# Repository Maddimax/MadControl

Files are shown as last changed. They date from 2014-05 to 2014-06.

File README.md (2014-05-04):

This contains all the files necessary to build your own Remote control ( or rather will soon )

# Hardware

The schematics and pcb files were created with [KiCad](http://www.kicad-pcb.org/display/KICAD/KiCad+EDA+Software+Suite)

# Software

All code was written with the standard Arduino IDE

# BOM 

Contains a list of all the components necessary

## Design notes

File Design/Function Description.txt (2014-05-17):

Screen:
	- 480x272
	- 32 bit ( 24 + 8 alpha )

Setup
- Calibrate
- Global Curves
	- Expo Display
		- Amount
	- Linear Display
		- Amount
	- Affected Channel checkboxes

- Analog InputChannels
	- Channel (x8)
		- Curves
			- Expo
			- Linear
			- 7-point
			- Result curve
		- Destination ( Output Channel / Function )
			- Liste
		- Settings
			- Bipolar / Unipolar
- Digital Input Channels
	- Channel (16)
		- Push/Switch - Button

- Macros
	- User mappings ( 8 )
		- Function Select: ( Liste )
			* Output channel ( 0-1024 )
				- Switch select
					- + Switch ( Select 0-16 )
					- - Switch ( Select 0-16 )
				- Num Values
					- Values

			* Trim(n) ( 0-1024 )
				- Switch select
					- + Switch ( Select 0-16 )
					- - Switch ( Select 0-16 )

			* Throttle Hold ( 0/1 )
				- Select Switch ( radio )
				- If button == Push
					* Hold / Toggle
				- If Button == Switch
					* -

- Output Channels ( 8+ )
	- Channel
		- Min/Max Werte

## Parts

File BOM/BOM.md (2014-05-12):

# Kits:

* Gameduino 2 		: (http://excamera.com/sphinx/gameduino2/)
* Arduino Mega 2560 : (http://arduino.cc/de/Main/ArduinoBoardMega2560)
* OrangeTx DIY      : [HK-OrangeTx-DIY-Module](http://www.hobbyking.com/hobbyking/store/__40205__OrangeRX_DSMX_DSM2_2_4GHz_DIY_Transmitter_Module.html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)

# Components

* LTC2309           : [HBE-Shop-LTC2309](https://hbe-shop.de/Art-2294612-LINEAR-TECHNOLOGY-LTC2309CFPBF-A-D-WANDLER)
* TCA9535           : [HBE-Shop-TCA9535](https://hbe-shop.de/Art-2335659-TEXAS-INSTRUMENTS-TCA9535PWR-I-O-EXPANDER-16BIT-I2C-SMBUS-TSSOP-24)
* 2 Axis Gimbal     : [Robotshop-GIM01](http://www.robotshop.com/eu/en/axis-joystick-gim.html)
* 10nf              : Ceramic SMD
* 0.1nf             : Ceramic SMD
* 2.2nf             : Ceramic SMD
* 10kΩ				: SMD
* 1.5kΩ				: SMD
* S1G (Diode)		: SMD
* Pin header        : [Conrad-PinHeader](http://www.conrad.de/ce/de/product/741146/Stiftleiste-RM-254-gerade-Pole-1-x-40-10120183-BKL-Electronic-Inhalt-1-St/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)
* Pin Header (f)    : [Conrad-PinHeader(f)](http://www.conrad.de/ce/de/product/740668/Einreihige-Buchsenleiste-RM-254-Pole-1-x-36-10120802-BKL-Electronic-Inhalt-1-St/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)

# Enclosures
* Shapeways         : TBD
* Thingyverse       : TBD

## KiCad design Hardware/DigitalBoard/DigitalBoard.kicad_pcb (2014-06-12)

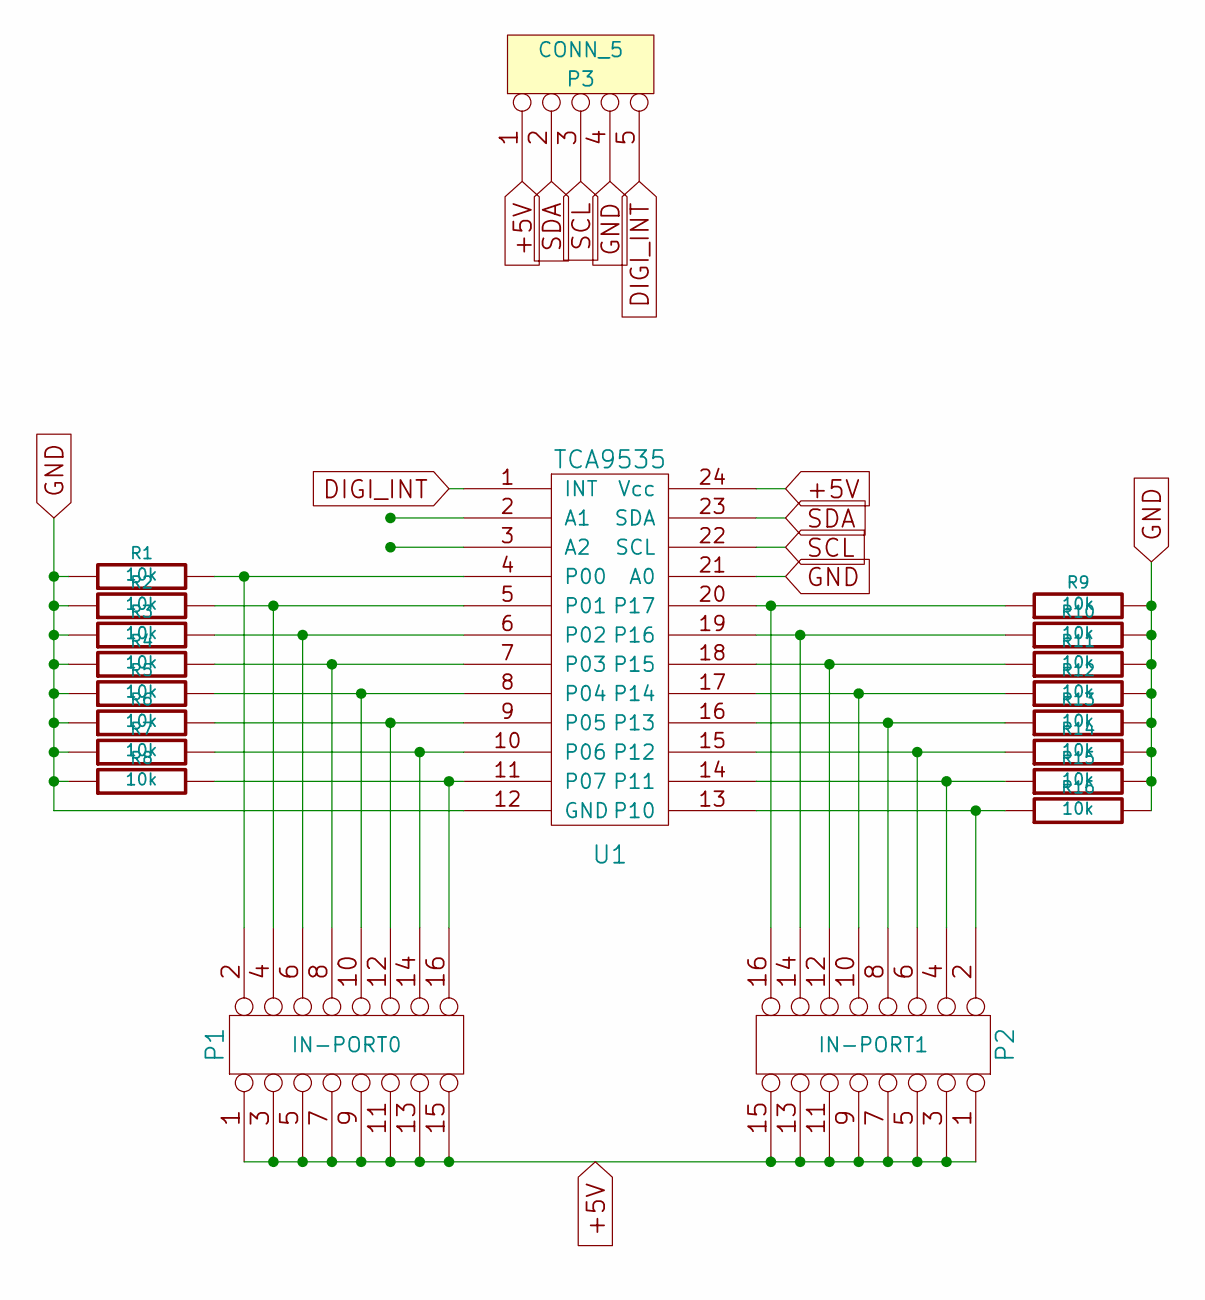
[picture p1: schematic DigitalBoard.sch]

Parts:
P1: IN-PORT0
P2: IN-PORT1
P3: CONN_5
R1, R2, R3, R4, R5, R6, R7, R8, R9, R10, R11, R12, R13, R14, R15, R16: 10k
U1: TCA9535

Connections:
+5V: P1.1, P1.3, P1.5, P1.7, P1.9, P1.11, P1.13, P1.15, P2.1, P2.3, P2.5, P2.7, P2.9, P2.11, P2.13, P2.15, P3.1, U1.24 (Vcc)
DIGI_INT: P3.5, U1.1 (INT)
GND: P3.4, R1.1, R2.1, R3.1, R4.1, R5.1, R6.1, R7.1, R8.1, R9.2, R10.2, R11.2, R12.2, R13.2, R14.2, R15.2, R16.2, U1.12 (GND), U1.21 (A0)
unnamed: P2.6, R14.1, U1.15 (P12)
unnamed: P1.6, R3.2, U1.6 (P02)
unnamed: P1.4, R2.2, U1.5 (P01)
unnamed: P1.12, R6.2, U1.9 (P05)
unnamed: P2.4, R15.1, U1.14 (P11)
unnamed: P2.2, R16.1, U1.13 (P10)
unnamed: P2.16, R9.1, U1.20 (P17)
unnamed: P2.14, R10.1, U1.19 (P16)
unnamed: P2.12, R11.1, U1.18 (P15)
unnamed: P2.10, R12.1, U1.17 (P14)
unnamed: P2.8, R13.1, U1.16 (P13)
unnamed: P1.16, R8.2, U1.11 (P07)
unnamed: P1.14, R7.2, U1.10 (P06)
unnamed: P1.10, R5.2, U1.8 (P04)
unnamed: P1.8, R4.2, U1.7 (P03)
unnamed: P1.2, R1.2, U1.4 (P00)
SCL: P3.3, U1.22 (SCL)
SDA: P3.2, U1.23 (SDA)

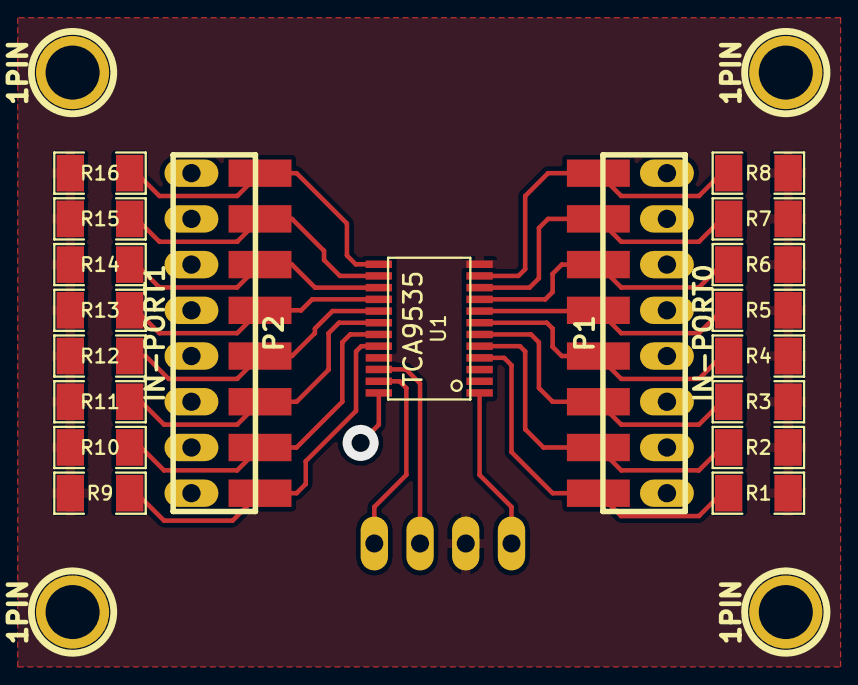
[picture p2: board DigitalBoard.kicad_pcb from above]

Board: 2 copper layers, 24 parts (1 on the bottom side), 21 nets.

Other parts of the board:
1PIN, 1PIN#2, 1PIN#3, 1PIN#4: P***; 1pin

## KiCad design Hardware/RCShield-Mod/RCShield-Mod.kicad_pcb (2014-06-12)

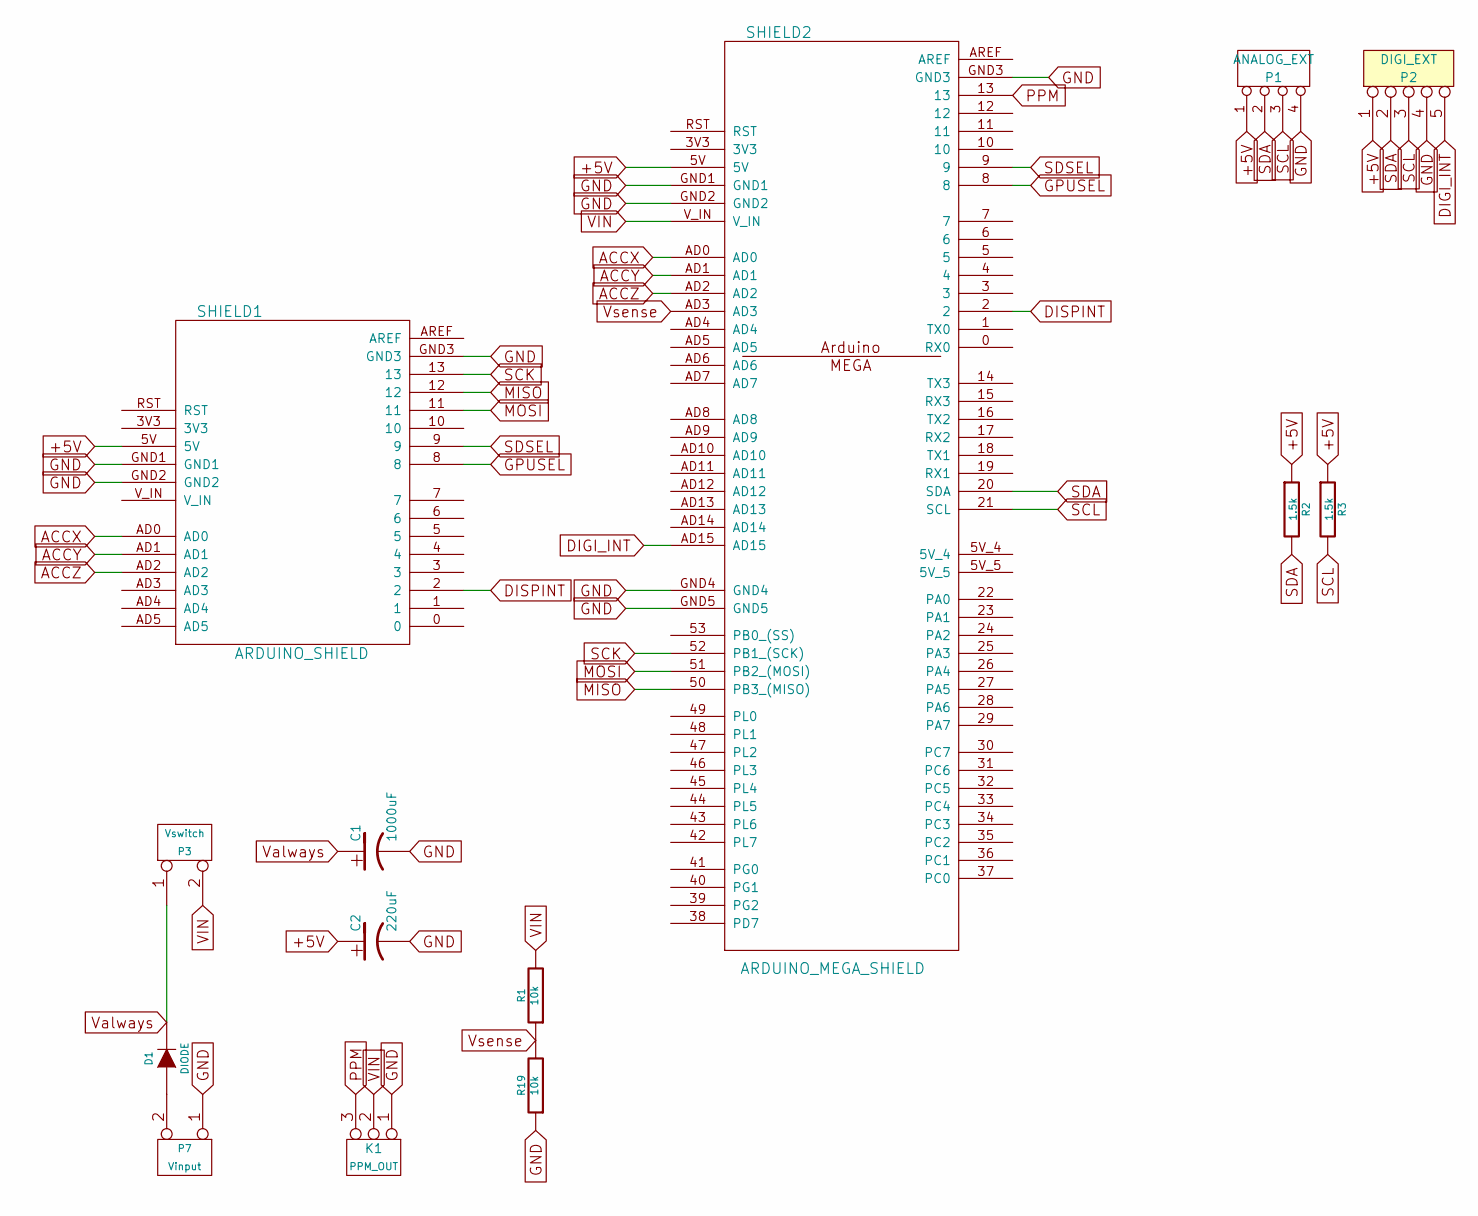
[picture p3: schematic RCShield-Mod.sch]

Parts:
C1: 1000uF
C2: 220uF
D1: DIODE
K1: PPM_OUT
P1: ANALOG_EXT
P2: DIGI_EXT
P3: Vswitch
P7: Vinput
R1, R19: 10k
R2, R3: 1.5k
SHIELD1: ARDUINO_SHIELD
SHIELD2: ARDUINO_MEGA_SHIELD

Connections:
+5V: C2.1, P1.1, P2.1, R2.1, R3.1, SHIELD1.5V, SHIELD2.5V
ACCX: SHIELD1.AD0, SHIELD2.AD0
ACCY: SHIELD1.AD1, SHIELD2.AD1
ACCZ: SHIELD1.AD2, SHIELD2.AD2
DIGI_INT: P2.5, SHIELD2.AD15
DISPINT: SHIELD1.2, SHIELD2.2
GND: C1.2, C2.2, K1.1, P1.4, P2.4, P7.1, R19.1, SHIELD1.GND1, SHIELD1.GND2, SHIELD1.GND3, SHIELD2.GND1, SHIELD2.GND2, SHIELD2.GND3, SHIELD2.GND4, SHIELD2.GND5
GPUSEL: SHIELD1.8, SHIELD2.8
MISO: SHIELD1.12, SHIELD2.50 (PB3_(MISO))
MOSI: SHIELD1.11, SHIELD2.51 (PB2_(MOSI))
unnamed: D1.1 (A), P7.2 (PM)
PPM: K1.3, SHIELD2.13
SCK: SHIELD1.13, SHIELD2.52 (PB1_(SCK))
SCL: P1.3, P2.3, R3.2, SHIELD2.21 (SCL)
SDA: P1.2, P2.2, R2.2, SHIELD2.20 (SDA)
SDSEL: SHIELD1.9, SHIELD2.9
VIN: K1.2 (PM), P3.2 (PM), R1.2, SHIELD2.V_IN
Valways: C1.1, D1.2 (K), P3.1
Vsense: R1.1, R19.2, SHIELD2.AD3

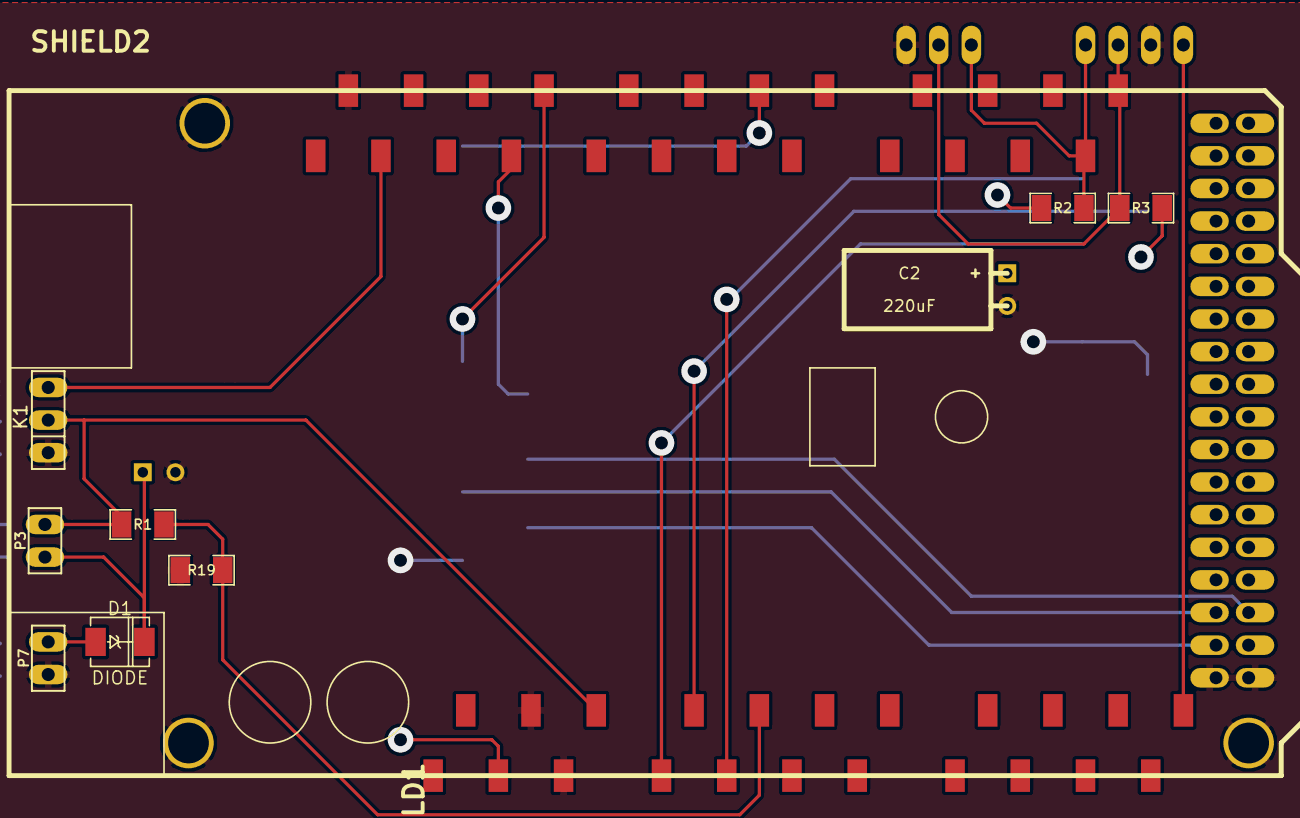
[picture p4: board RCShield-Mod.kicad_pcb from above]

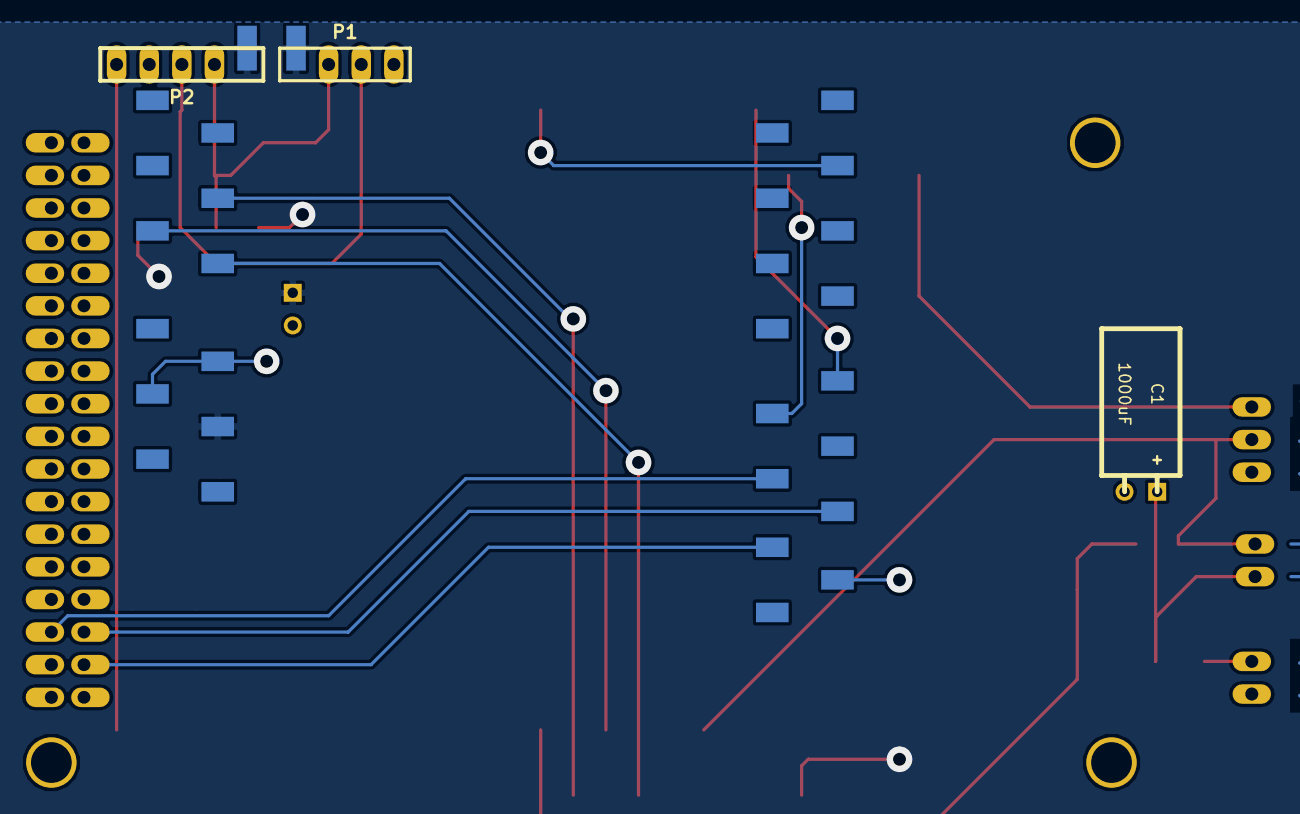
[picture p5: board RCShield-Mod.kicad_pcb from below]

Board: 2 copper layers, 14 parts (3 on the bottom side), 19 nets.

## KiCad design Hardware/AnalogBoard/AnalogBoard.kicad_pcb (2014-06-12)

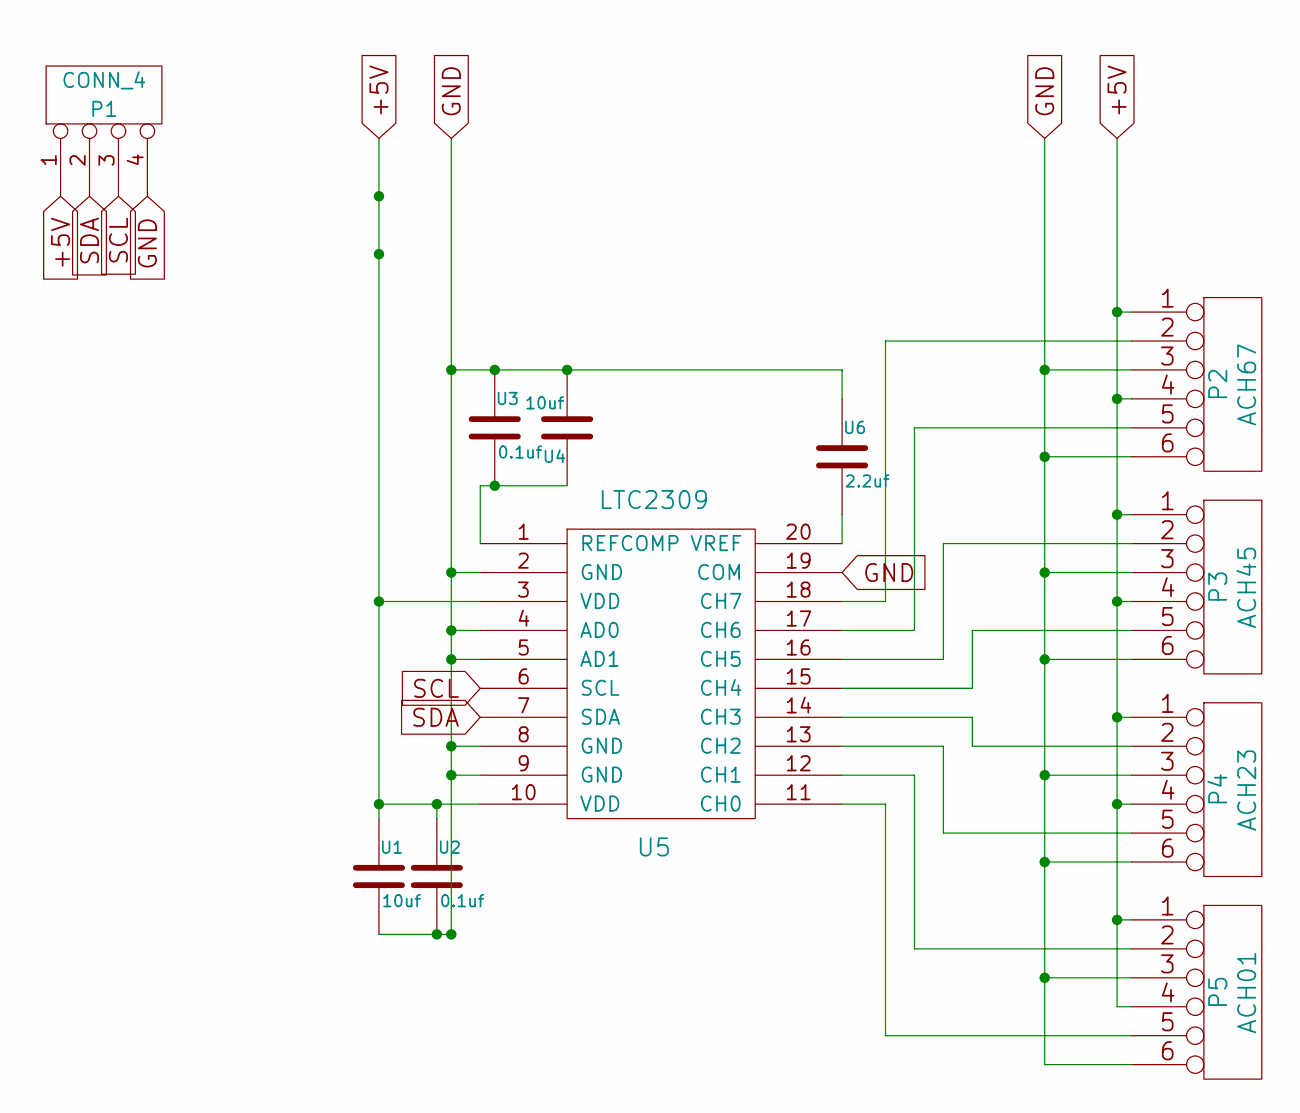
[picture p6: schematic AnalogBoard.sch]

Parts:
P1: CONN_4
P2: ACH67
P3: ACH45
P4: ACH23
P5: ACH01
U1, U4: 10uf
U2, U3: 0.1uf
U5: LTC2309
U6: 2.2uf

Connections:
+5V: P1.1, P2.1, P2.4, P3.1, P3.4, P4.1, P4.4, P5.1, P5.4, U1.1, U2.1, U5.3 (VDD), U5.10 (VDD)
GND: P1.4, P2.3, P2.6, P3.3, P3.6, P4.3, P4.6, P5.3, P5.6, U1.2, U2.2, U3.1, U4.2, U5.2 (GND), U5.4 (AD0), U5.5 (AD1), U5.8 (GND), U5.9 (GND), U5.19 (COM), U6.1
unnamed: P5.5, U5.11 (CH0)
unnamed: P4.2, U5.14 (CH3)
unnamed: P2.5, U5.17 (CH6)
unnamed: P3.2, U5.16 (CH5)
unnamed: P3.5, U5.15 (CH4)
unnamed: P4.5, U5.13 (CH2)
unnamed: P5.2, U5.12 (CH1)
unnamed: U5.20 (VREF), U6.2
unnamed: U3.2, U4.1, U5.1 (REFCOMP)
unnamed: P2.2, U5.18 (CH7)
SCL: P1.3, U5.6 (SCL)
SDA: P1.2, U5.7 (SDA)

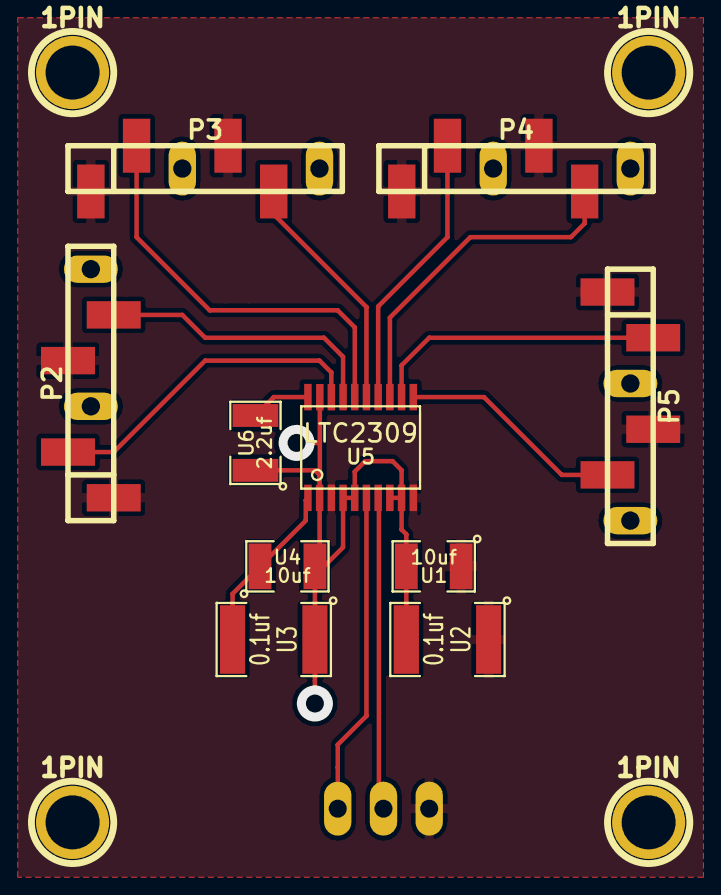
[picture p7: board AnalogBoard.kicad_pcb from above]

Board: 2 copper layers, 15 parts (1 on the bottom side), 14 nets.

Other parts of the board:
1PIN, 1PIN#2, 1PIN#3, 1PIN#4: P***; 1pin

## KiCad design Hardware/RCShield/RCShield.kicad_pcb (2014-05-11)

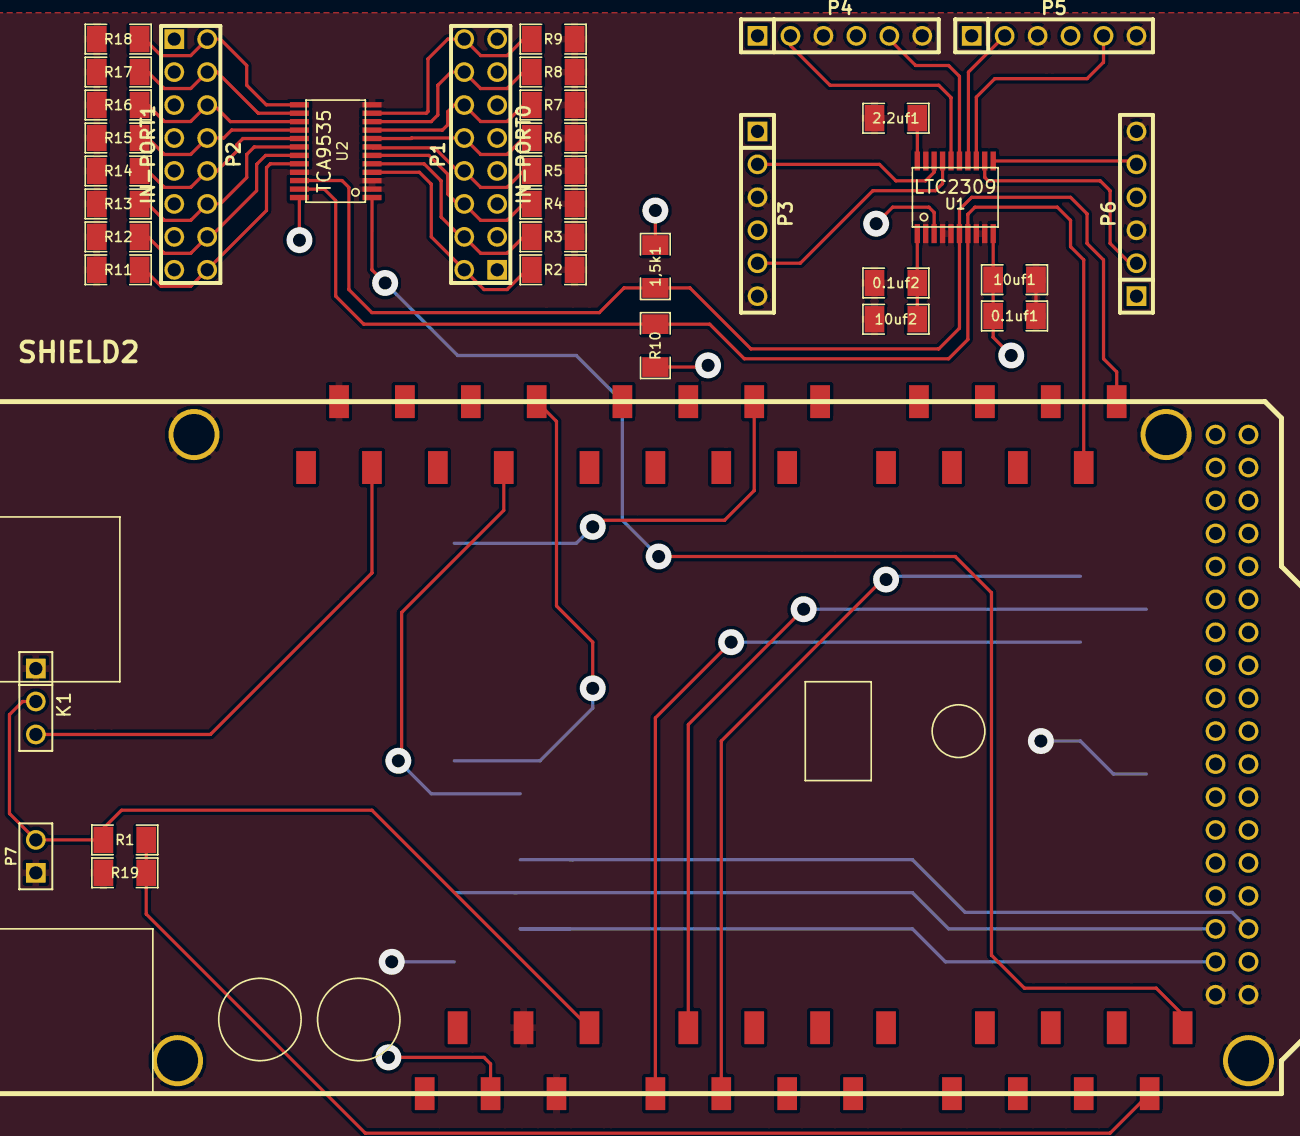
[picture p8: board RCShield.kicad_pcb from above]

Board: 2 copper layers, 37 parts (0 on the bottom side), 43 nets.

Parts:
0.1uf1, 0.1uf2, 2.2uf1, 10uf1, 10uf2: C; SM1206
1,5k1: 1,5k; SM1206
K1: PPM_OUT; PIN_ARRAY_3X1
P1: IN-PORT0; pin_array_8x2
P2: IN-PORT1; pin_array_8x2
P3: ACH67; PIN_ARRAY-6X1
P4: ACH45; PIN_ARRAY-6X1
P5: ACH23; PIN_ARRAY-6X1
P6: ACH01; PIN_ARRAY-6X1
P7: Vinput; PIN_ARRAY_2X1
R1, R2, R3, R4, R5, R6, R7, R8, R9, R11, R12, R13, R14, R15, R16, R17, R18, R19: 10k; SM1206
R10: 1,5k; SM1206
SHIELD1: ARDUINO_SHIELD; ARDUINO_SHIELD_SMD
SHIELD2: ARDUINO_MEGA_SHIELD; ARDUINO_MEGA_SHIELD_SMD
U1: LTC2309; tssop-20
U2: TCA9535; tssop-24

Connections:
+5V: 0.1uf1.1, 1,5k1.2, 10uf1.1, P1.1, P1.3, P1.5, P1.7, P1.9, P1.11, P1.13, P1.15, P2.1, P2.3, P2.5, P2.7, P2.9, P2.11, P2.13, P2.15, P3.1, P3.4, P4.1, P4.4, P5.1, P5.4, P6.1, P6.4, R10.2, SHIELD1.5V, SHIELD2.5V, U1.3, U1.10, U2.24
ACCX: SHIELD1.AD0, SHIELD2.AD0
ACCY: SHIELD1.AD1, SHIELD2.AD1
ACCZ: SHIELD1.AD2, SHIELD2.AD2
DIGI_INT: SHIELD2.AD15, U2.1
DISPINT: SHIELD1.2, SHIELD2.2
GND: 0.1uf1.2, 0.1uf2.1, 2.2uf1.1, 10uf1.2, 10uf2.2, K1.1, P3.3, P3.6, P4.3, P4.6, P5.3, P5.6, P6.3, P6.6, P7.1, R2.1, R3.1, R4.1, R5.1, R6.1, R7.1, R8.1, R9.1, R11.2, R12.2, R13.2, R14.2, R15.2, R16.2, R17.2, R18.2, R19.1, SHIELD1.GND1, SHIELD1.GND2, SHIELD1.GND3, SHIELD2.GND1, SHIELD2.GND2, SHIELD2.GND3, SHIELD2.GND4, SHIELD2.GND5, U1.2, U1.4, U1.5, U1.8, U1.9, U1.19, U2.2, U2.3, U2.12, U2.21
GPUSEL: SHIELD1.8, SHIELD2.8
MISO: SHIELD1.12, SHIELD2.50
MOSI: SHIELD1.11, SHIELD2.51
unnamed: P3.2, U1.18
unnamed: P6.2, U1.12
unnamed: P6.5, U1.11
unnamed: P4.5, U1.15
unnamed: P3.5, U1.17
unnamed: P4.2, U1.16
unnamed: P5.2, U1.14
unnamed: P5.5, U1.13
unnamed: 0.1uf2.2, 10uf2.1, U1.1
unnamed: 2.2uf1.2, U1.20
unnamed: P1.8, R5.2, U2.7
unnamed: P2.4, R17.1, U2.14
unnamed: P1.16, R9.2, U2.11
unnamed: P1.14, R8.2, U2.10
unnamed: P1.12, R7.2, U2.9
unnamed: P1.10, R6.2, U2.8
unnamed: P2.2, R18.1, U2.13
unnamed: P1.2, R2.2, U2.4
unnamed: P1.6, R4.2, U2.6
unnamed: P1.4, R3.2, U2.5
unnamed: P2.14, R12.1, U2.19
unnamed: P2.16, R11.1, U2.20
unnamed: P2.12, R13.1, U2.18
unnamed: P2.10, R14.1, U2.17
unnamed: P2.8, R15.1, U2.16
unnamed: P2.6, R16.1, U2.15
PPM: K1.3, SHIELD2.13
SCK: SHIELD1.13, SHIELD2.52
SCL: 1,5k1.1, SHIELD2.21, U1.6, U2.22
SDA: R10.1, SHIELD2.20, U1.7, U2.23
SDSEL: SHIELD1.9, SHIELD2.9
VIN: K1.2, P7.2, R1.2, SHIELD2.V_IN
Vsense: R1.1, R19.2, SHIELD2.AD14

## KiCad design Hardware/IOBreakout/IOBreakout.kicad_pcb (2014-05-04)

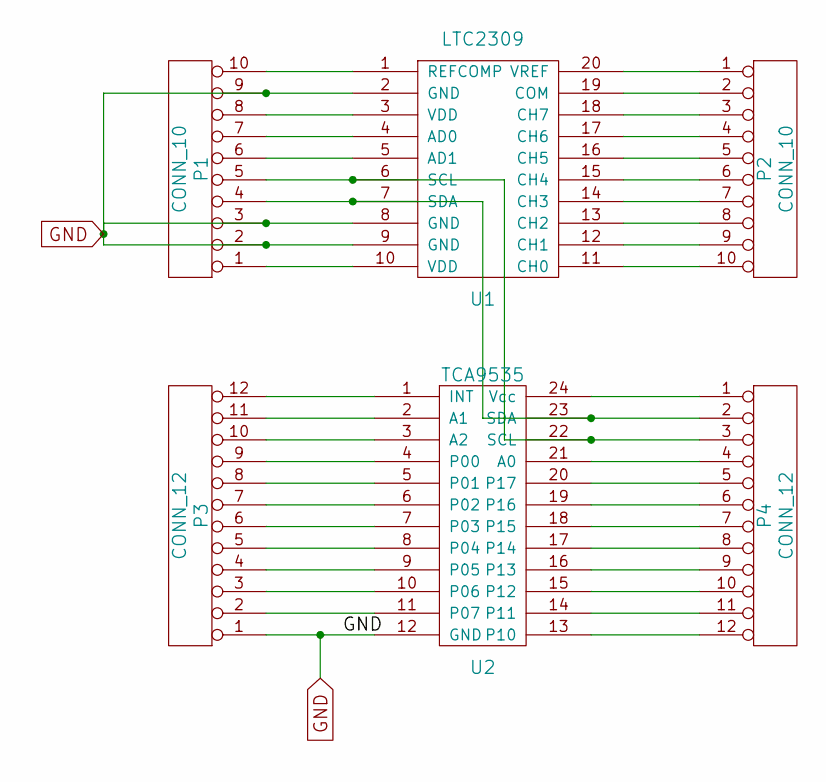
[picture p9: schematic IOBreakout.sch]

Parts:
P1, P2: CONN_10
P3, P4: CONN_12
U1: LTC2309
U2: TCA9535

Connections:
GND: P1.2, P1.3, P1.9, P3.1, U1.2 (GND), U1.8 (GND), U1.9 (GND), U2.12 (GND)
unnamed: P3.8, U2.5 (P01)
unnamed: P3.2, U2.11 (P07)
unnamed: P3.3, U2.10 (P06)
unnamed: P3.4, U2.9 (P05)
unnamed: P3.5, U2.8 (P04)
unnamed: P3.6, U2.7 (P03)
unnamed: P3.7, U2.6 (P02)
unnamed: P3.9, U2.4 (P00)
unnamed: P3.10, U2.3 (A2)
unnamed: P3.11, U2.2 (A1)
unnamed: P3.12, U2.1 (INT)
unnamed: P4.1, U2.24 (Vcc)
unnamed: P4.4, U2.21 (A0)
unnamed: P4.12, U2.13 (P10)
unnamed: P4.11, U2.14 (P11)
unnamed: P4.10, U2.15 (P12)
unnamed: P4.5, U2.20 (P17)
unnamed: P4.6, U2.19 (P16)
unnamed: P4.7, U2.18 (P15)
unnamed: P4.8, U2.17 (P14)
unnamed: P4.9, U2.16 (P13)
unnamed: P1.10, U1.1 (REFCOMP)
unnamed: P2.2, U1.19 (COM)
unnamed: P2.3, U1.18 (CH7)
unnamed: P1.1, U1.10 (VDD)
unnamed: P1.8, U1.3 (VDD)
unnamed: P1.7, U1.4 (AD0)
unnamed: P1.6, U1.5 (AD1)
unnamed: P1.5, P4.3, U1.6 (SCL), U2.22 (SCL)
unnamed: P1.4, P4.2, U1.7 (SDA), U2.23 (SDA)
unnamed: P2.1, U1.20 (VREF)
unnamed: P2.8, U1.13 (CH2)
unnamed: P2.7, U1.14 (CH3)
unnamed: P2.6, U1.15 (CH4)
unnamed: P2.5, U1.16 (CH5)
unnamed: P2.4, U1.17 (CH6)
unnamed: P2.9, U1.12 (CH1)
unnamed: P2.10, U1.11 (CH0)

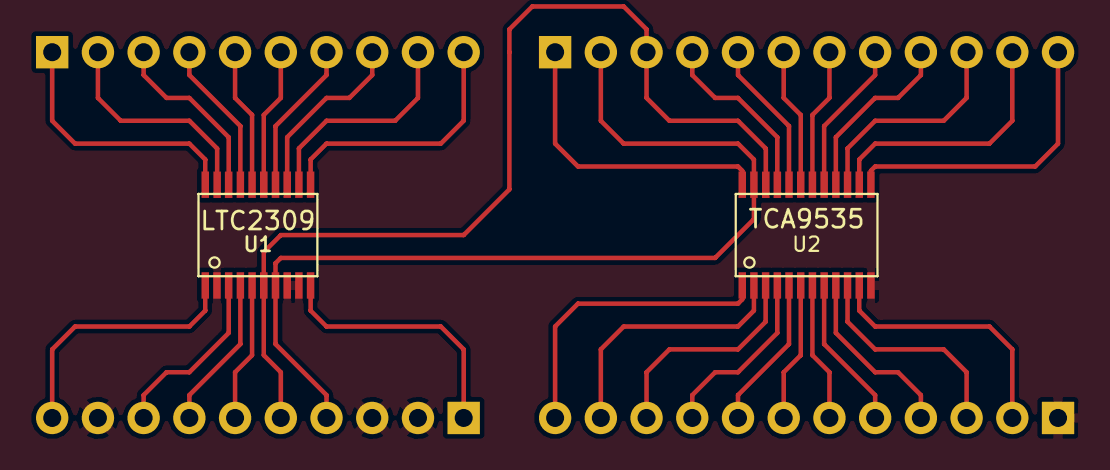
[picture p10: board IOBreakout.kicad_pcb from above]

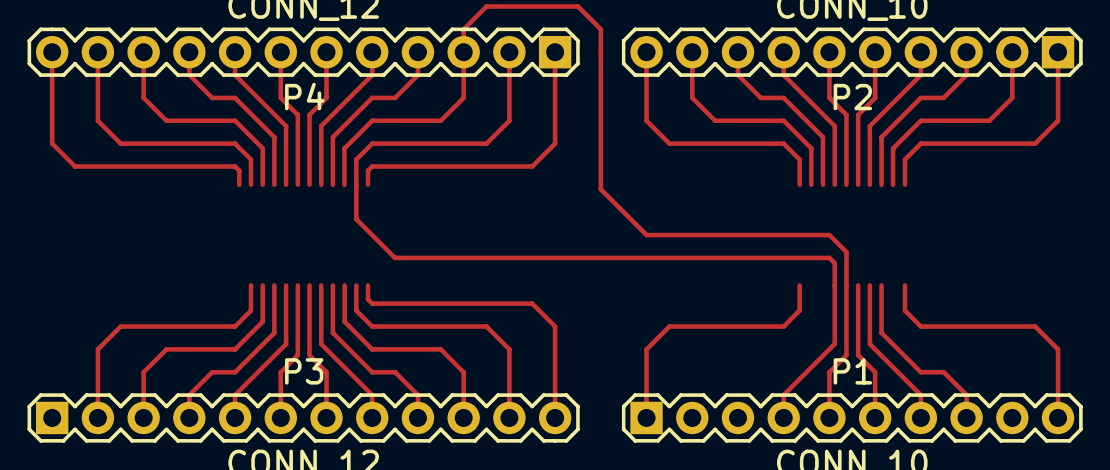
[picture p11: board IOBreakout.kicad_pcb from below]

Board: 2 copper layers, 6 parts (4 on the bottom side), 39 nets.

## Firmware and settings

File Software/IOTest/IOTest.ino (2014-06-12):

#define VERBOSE 1

#include <EEPROM.h>
#include <SPI.h>
#include <GD2.h>
#include <Wire.h>

#include <PinChangeInt.h>
#include <PinChangeIntConfig.h>

#include "TCA9535.h"
#include "LTC2309.h"

#include "powlut.h"

#include "Color.h"


#include "ExpoFilter.h"
#include "PointCurveFilter.h"
#include "LinearFilter.h"

const int kAddr9535 = 0x20;
const int kAddr2309 = 0x08;

#define NUM_INCHANNELS 5
#define NUM_TX_CHANNELS 8

byte adcChannelRemap[8] = {
  4,
  5,
  6, 
  7,
  1,
  0,
  2,
  3
};

#define PPM_OUT_PIN 13
#define PPM_MIN_VALUE 1000
#define PPM_MAX_VALUE 2024

#define VSENSE_PIN A3

#define CHANNEL_CALIBRATION_MAGIC NUM_INCHANNELS + 0xA0
#define POINT_CURVE_FILTER_NUM_POINTS 7

#include "PPMGen.h"
#include "Vsense.h"

#include "ADCChannel.h"
#include "ADCChannels.h"


#include "InputChannel.h"
#include "InputChannels.h"

//TCA9535 digiIo(kAddr9535);
LTC2309 analogIn(kAddr2309);

TADCChannels adcChannels(&analogIn);
TInputChannels inChannels;

struct Palette
{
  Color bgColor;
  Color text;
};

Palette palette = {
  Color( 128, 128, 128, 255 ),
  Color( 255, 255, 255, 255 )
};


#include "ChannelWidget.h"
#include "ChannelMeter.h"
#include "XYWidget.h"
#include "Button.h"

#include "MainScreen.h"
#include "CalibrationScreen.h"



/////////////////////////////////////////////////////////
// EEPROM Layout:
// 0-24 => Gameduino Calibration
// 25 => 0xA0 if channels are calibrated
// 26-xx => Channel data

void setup() {

  // put your setup code here, to run once:
  Serial.begin(115200);
  
  PPMGen::begin();

  Wire.begin();

#ifdef LTC2309_CALC_FLOAT
  analogIn.calibrate(0x64A, 0xa9F, 0.0, 1.0);
#endif

  //digiIo.begin();

  //digiIo.configuration(0).value = 0x00;
  //digiIo.configuration(1).value = 0x01;
  //digiIo.writeConfiguration();

  //InterruptHelper::begin(A15);

  for(int i=1;i<4;i++)
  {
    inChannels.channel(i)->setBipolar(true);
    inChannels.channel(i)->expoFilter()->setEnabled(true);
    inChannels.channel(i)->expoFilter()->setAmount(0.5);
  }

  inChannels.channel(2)->expoFilter()->setEnabled(false);
  inChannels.channel(2)->pointCurveFilter()->setEnabled(true);
  inChannels.channel(2)->pointCurveFilter()->setPoint(0, 0.1);
  inChannels.channel(2)->pointCurveFilter()->setPoint(1, 0.25);
  inChannels.channel(2)->pointCurveFilter()->setPoint(2, 0.7);
  inChannels.channel(2)->pointCurveFilter()->setPoint(3, 0.8);
  inChannels.channel(2)->pointCurveFilter()->setPoint(4, 0.9);


  GD.begin();
}

int i=0;

uint16_t s_currentScreen = 0;
float dur = 0.0f;

unsigned long lastTime = millis();

void loop() {

  unsigned long newTime = millis();

  dur = (dur*0.9f) + ((float)(newTime - lastTime)*0.1f);

  lastTime = newTime;

  //InterruptHelper::process(&digiIo);
  adcChannels.update();
  inChannels.updateFromAdc(adcChannels);

  inChannels.globalExpo()->setEnabled(true);
  inChannels.globalExpo()->setAmount( inChannels.channel(4)->value() );
  
  
  PPMGen::setPPMValue(1, 0.5f);//inChannels.channelValue(0));

  GD.get_inputs();

  if(adcChannels.isCalibrating())
  {
    CalibrationScreen::loop();
  }
  else
  {
    if(s_currentScreen == 0)
    {
      MainScreen::loop();
    }
  }

  palette.text.apply();
  GD.cmd_number(480-30,0, 26, 0, 1000.0/dur);
  
  char vMsg[20];
  
  float volts = Vsense::getInputVoltage();
  
  int i = floor(volts);
  volts -= (float)i;
  int r = (int)(volts*10.0f);
  
  sprintf(vMsg, "%i.%iv", i, r);
  
  GD.cmd_text(480-30, 32, 26, 0, vMsg);

  GD.swap();

  i++;
  


}

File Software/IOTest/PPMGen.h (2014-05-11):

#pragma once

//////////////////////CONFIGURATION///////////////////////////////
#define default_servo_value 1500  //set the default servo value
#define PPM_FrLen 22500  //set the PPM frame length in microseconds (1ms = 1000µs)
#define PPM_PulseLen 300  //set the pulse length
#define onState 1  //set polarity of the pulses: 1 is positive, 0 is negative
//////////////////////////////////////////////////////////////////

namespace PPMGen
{
  int s_ppmValues[NUM_TX_CHANNELS];
  
  void begin()
  {
    //initiallize default ppm values
    for(int i=0; i<NUM_TX_CHANNELS; i++){
      s_ppmValues[i]= default_servo_value;
    }
    
    pinMode(PPM_OUT_PIN, OUTPUT);
    digitalWrite(PPM_OUT_PIN, !onState);  //set the PPM signal pin to the default state (off)
    
    cli();
    TCCR1A = 0; // set entire TCCR1 register to 0
    TCCR1B = 0;
    
    OCR1A = 100;  // compare match register, change this
    TCCR1B |= (1 << WGM12);  // turn on CTC mode
    TCCR1B |= (1 << CS11);  // 8 prescaler: 0,5 microseconds at 16mhz
    TIMSK1 |= (1 << OCIE1A); // enable timer compare interrupt
    sei();
  }
  
  void setPPMValue(byte channelNumber, int value)
  {
    s_ppmValues[channelNumber] = value;
  }
  
  void setPPMValue(byte channelNumber, float value)
  {
    int v = (value*(float)(PPM_MAX_VALUE - PPM_MIN_VALUE)) + PPM_MIN_VALUE;
    setPPMValue(channelNumber, v); 
  }
  
  
}


ISR(TIMER1_COMPA_vect){  //leave this alone
  static boolean state = true;
  
  TCNT1 = 0;
  
  if(state) {  //start pulse
    digitalWrite(PPM_OUT_PIN, onState);
    OCR1A = PPM_PulseLen * 2;
    state = false;
    
  }
  else{  //end pulse and calculate when to start the next pulse
    static byte cur_chan_numb;
    static unsigned int calc_rest;
  
    digitalWrite(PPM_OUT_PIN, !onState);
    state = true;

    if(cur_chan_numb >= NUM_TX_CHANNELS){
    //digitalWrite(9, HIGH);
      cur_chan_numb = 0;
      calc_rest = calc_rest + PPM_PulseLen;// 
      OCR1A = (PPM_FrLen - calc_rest) * 2;
      calc_rest = 0;
    }
    else{
    //digitalWrite(9, LOW);
      OCR1A = (PPMGen::s_ppmValues[cur_chan_numb] - PPM_PulseLen) * 2;
      calc_rest = calc_rest + PPMGen::s_ppmValues[cur_chan_numb];
      cur_chan_numb++;
    }     
  }
}

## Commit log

2014-05-04 * Adding the IO Breakout board
    [IOBreakout.kicad_pcb, IOBreakout.sch]
2014-05-04 * Added initial BOM
2014-05-04 Adding python powerlut utility Renaming Channels to ADCChannels
2014-05-04 Fixing path case
2014-05-05 Changed "Unipolar" to "Bipolar" Created point curve filter with variable number of points Added Linear Filter ( Dual Rate )
2014-05-05 Added Palette Added Button widget Added XYWidget Updated Mainscreen Started Setup screen Improved ExpoFilter Performance Fixed LinearFilter amount Switched to 7 step PointCurve
    [IOTest.ino]
2014-05-09 First iteration of the RC shield
    [RCShield.sch]
2014-05-11 Connected I2C Components on the PCB
    [RCShield.sch]
2014-05-11 Adding Vsense and PPM Generator Adding PCB File
    [RCShield.kicad_pcb, RCShield.sch]
2014-05-11 Changed cap footprints
2014-05-11 Creating Breakout boards for the IO's ( not in main shield yet )
    [AnalogBoard.kicad_pcb, AnalogBoard.sch, DigitalBoard.kicad_pcb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]
2014-05-12 Adding modular mainboard
    [RCShield-Mod.kicad_pcb, RCShield-Mod.sch]
2014-05-12 Changing VIA Size for the Analog Board Moving Analog Board away from Digital board connector
    [AnalogBoard.kicad_pcb, RCShield-Mod.kicad_pcb, RCShield.sch]
2014-05-12 * Updating BOM
2014-05-17 Updated PCB to make it more DIY friendly Changed Vsense pin to A3 Added Design Folder
    [AnalogBoard.kicad_pcb, DigitalBoard.kicad_pcb, RCShield-Mod.kicad_pcb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]
2014-05-19 Adding Filter Cap to main board Adding ADC Channel re-map Disabling digital IO Configuration in preparation for the new breakout board.
    [RCShield-Mod.kicad_pcb, RCShield-Mod.sch]
2014-06-12 * Updating PCB to more rectangular + Caps + On/Off Switch * Disabling Digital Breakout board for now
    [AnalogBoard.kicad_pcb, DigitalBoard.kicad_pcb, RCShield-Mod.kicad_pcb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]
